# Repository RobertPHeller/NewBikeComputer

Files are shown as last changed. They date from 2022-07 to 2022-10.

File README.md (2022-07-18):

# New Bike Computer.

Based on the Adafruit ESP32-S3 TFT Feather, with an Adafruit Ultimate GPS
FeatherWing. Displays date/time, Lat/Lon, Heading, Alt., MPH/Miles, Battery
voltage. Saves trip info on SPIFFS, which is uploadable via USB.

This is an update to my older Ardunio Uno based unit. Improvements include the
GPS for location, time, heading, and altitude.  Using a 32-bit MCU and using 
FLASH SPIFFS to store trip information, as a CSV file, which can be uploaded
to a host computer via USB.  This version will be better weatherproofed (the 
old one's LCD display has been partially water damaged).

Files in this project:

NewBikeComputer.fzz -- this is the Fritzing for the circuit breadboard.  The 
circuit is pretty simple and straightforward.  If you don't have Fritzing, 
there is an image (NewBikeComputer_bb.png) of the breadboard and a PDF 
(NewBikeComputer_Schematic.pdf) of the schematic.  Parts placement is not 
critical.  Oh, the 100K resistor should be 107K: it and the 33K are 1% 
resistors that form a voltage divider to measure the battery voltage.  My 
trike has a 12V gell cell battery for the lights (headlights, marker lights, 
brake lights, and turn turn signals), that I am also using to power the bike 
computer.  If you are doing something else, feel free to modify things to 
suit.  If you use a LiPo, you can use the built-in JST connector and I believe 
there is a built in battery monitor circuit, so you should change that part of 
the code and leave off the 12V power supply, DC power jack, and the voltage 
divider resistors.

NewBikeComputer_bb.png -- Breadboard image

NewBikeComputer_Schematic.pdf -- Schematic

NewBikeComputer/ -- this sub-directorty contains the Arduino code:

- NewBikeComputer.ino This is the main program
- BikeNVS.h This is the NVS (EEProm) handling
- Button.cpp Button class
- Button.h   Button class
- Modes.cpp  Mode Button class
- Modes.h    Mode Button class
- PersistentTripDatabase.cpp Trip file handling
- PersistentTripDatabase.h   Trip file handling
- SerialCLI.cpp Serial CLI handling
- SerialCLI.h   Serial CLI handling
- Wheelsensor.cpp Wheel sensor
- Wheelsensor.h   Wheel sensor

Libraries needed: the Adafruit ST7735 and ST7789 library, the Adafruit GPS
library, the Adafruit BusIO library, and the Adafruit GFX (the last two will 
be pulled in by the first two).  If you use a LiPo battery and want to use the 
internal battery monitor, you will need to modify the code and add the  
Adafruit LC709203F library as well.

BikeHost/ -- this sub-directorty contains the host code.  This is a Tcl/Tk 
program that runs on a host computer to allow for some maintainance tasks and 
to upload the trip file.  It is set up to build under Linux for a Linux 
target. Note: the Arduino Serial Monitor could also be used for these 
functions.

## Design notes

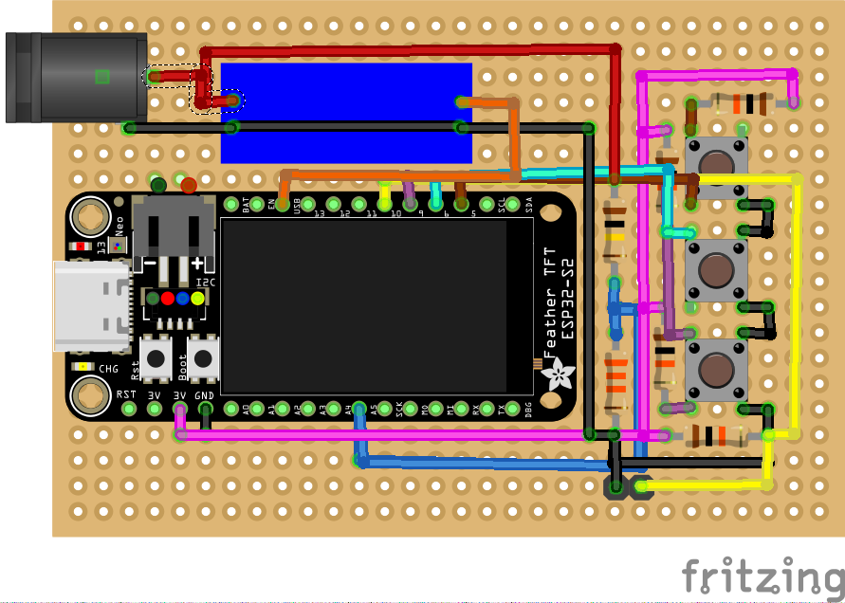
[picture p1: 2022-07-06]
NewBikeComputer_bb.png

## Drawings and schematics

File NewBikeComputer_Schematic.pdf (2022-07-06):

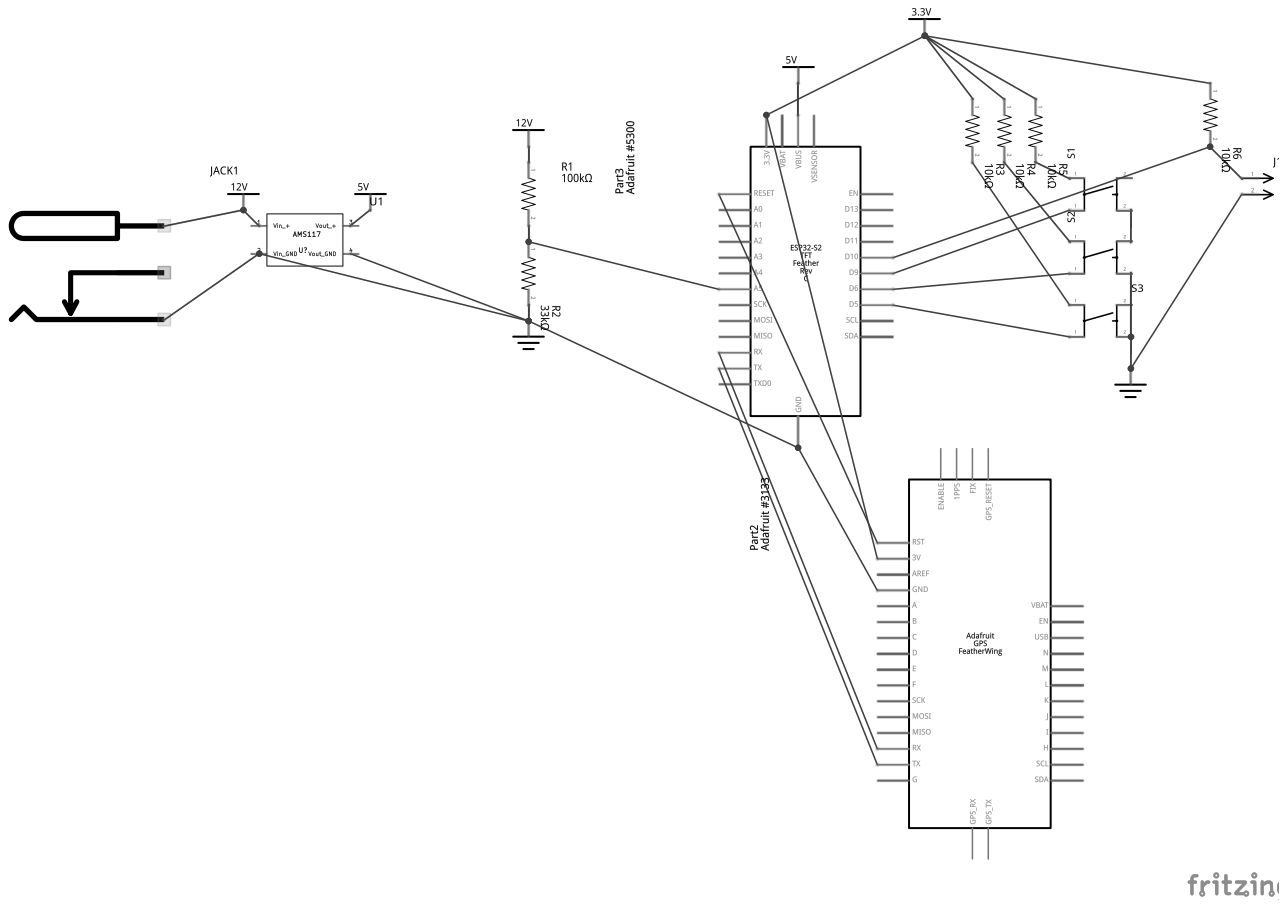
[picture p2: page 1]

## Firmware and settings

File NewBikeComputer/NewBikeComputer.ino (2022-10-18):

// -!- C++ -!- //////////////////////////////////////////////////////////////
//
//  System        : 
//  Module        : 
//  Object Name   : $RCSfile$
//  Revision      : $Revision$
//  Date          : $Date$
//  Author        : $Author$
//  Created By    : Robert Heller
//  Created       : Thu Jun 30 15:03:26 2022
//  Last Modified : <221018.1304>
//
//  Description	
//
//  Notes
//
//  History
//	
/////////////////////////////////////////////////////////////////////////////
//
//    Copyright (C) 2022  Robert Heller D/B/A Deepwoods Software
//			51 Locke Hill Road
//			Wendell, MA 01379-9728
//
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
// 
//
//////////////////////////////////////////////////////////////////////////////

static const char rcsid[] = "@(#) : $Id$";

#include <Arduino.h>
#include <stdio.h>
#include <Adafruit_GFX.h>    // Core graphics library
#include <Adafruit_ST7789.h> // Hardware-specific library for ST7789
#include <SPI.h>
#include <Adafruit_GPS.h>
#include <Fonts/FreeMono12pt7b.h> // 13x14 (WxH) Spacing: 14 NL: 24 -- 17c x 5l
#include <Fonts/FreeMono24pt7b.h> // 26x26 (WxH) Spacing: 28 NL: 47 -- 8c  x 2l
#include <HardwareSerial.h>
#include <FS.h>
#include <SPIFFS.h>
#include "Wheelsensor.h"
#include "Button.h"
#include "Modes.h"
#include "SerialCLI.h"
#include "PersistentTripDatabase.h"
#include "BikeNVS.h"

const uint8_t BUTTON2 = 9;
const uint8_t BUTTON3 = 6;
const uint8_t MODE  = 5;
const uint8_t WHEEL = 10;
const uint8_t BATTERY = A5;

Adafruit_GPS GPS(&Serial1);


ModeButton b1(MODE);
Button b2(BUTTON2);
Button b3(BUTTON3);
Wheelsensor WheelSensor(WHEEL);

// Use dedicated hardware SPI pins
Adafruit_ST7789 tft = Adafruit_ST7789(TFT_CS, TFT_DC, TFT_RST);
GFXcanvas16 canvas(240, 135);

PersistentTripDatabase tripdatabase(&GPS);

constexpr float VScale = 14.0/4095.0;

static     char buffer[40];

BikeNVS NVS;

static int TickCounter = 0;

void setup() {
    // put your setup code here, to run once:
    // Initialize serial first (so we can debug stuff)
    Serial.begin(115200);
    NVS.begin();
    // 9600 NMEA is the default baud rate for Adafruit MTK GPS's- some use 4800
    Serial1.begin(9600,SERIAL_8N1,RX,TX);
    delay(10);
    //GPS.begin(9600);
    GPS.sendCommand(PMTK_SET_NMEA_OUTPUT_RMCGGA);
    // Set the update rate
    GPS.sendCommand(PMTK_SET_NMEA_UPDATE_1HZ);   // 1 Hz update rate
    GPS.sendCommand(PMTK_API_SET_FIX_CTL_100_MILLIHERTZ);
    GPS.sendCommand(PGCMD_ANTENNA);
    delay(1000);
    GPS.sendCommand(PMTK_Q_RELEASE);
    WheelSensor.init(NVS.Miles());
    //analogReference(DEFAULT);
    // turn on backlite
    pinMode(TFT_BACKLITE, OUTPUT);
    digitalWrite(TFT_BACKLITE, HIGH);
    
    // turn on the TFT / I2C power supply
    pinMode(TFT_I2C_POWER, OUTPUT);
    digitalWrite(TFT_I2C_POWER, HIGH);
    delay(10);
    
    // initialize TFT
    tft.init(135, 240); // Init ST7789 240x135
    tft.setRotation(3);
    tft.fillScreen(ST77XX_BLACK);
    tripdatabase.begin(WheelSensor.Miles(),NVS.TZOffset());
    Serial.println("BikeComputer 0.0");
    Serial.print(">>");
    Serial.flush();
    TickCounter = 0;
}

void loop() {
    // put your main code here, to run repeatedly:
    // Get battery Voltage:
    float VBatt = analogRead(BATTERY) * VScale;
    int   VBint = (int)VBatt;
    int   VBfract = (int)((VBatt - VBint)*10);
    // Process any Serial CLI requests.
    if (Serial.available() > 0) {
        ProcessSerialCLI(&tripdatabase,&NVS,&WheelSensor);
    }
    // Read Wheel sensor and compute MPH
    int speed = 0;
    if (WheelSensor.CheckState()) {
        speed = WheelSensor.CurrentSpeed();
    }
    DisplayMode mode = TimeAndSpeed;
    //DisplayMode mode = b1.CheckModeButton();
    bool newtrip = false;
    // if (b2.Pressed()) newtrip = true;
    bool final   = false;
    // if (b3.Pressed()) final = true;
    tripdatabase.UpdateTripRecord(WheelSensor.Miles(),newtrip,final);
    canvas.fillScreen(ST77XX_BLACK);
    canvas.setFont(&FreeMono12pt7b);
    canvas.setCursor(0, 18);
    canvas.setTextColor(ST77XX_RED);
    canvas.println(tripdatabase.TimeHeader());
    canvas.setTextColor(ST77XX_YELLOW);
    canvas.println(tripdatabase.Location());
    canvas.println(tripdatabase.Heading());
    canvas.setTextColor(ST77XX_WHITE);
    canvas.setFont(&FreeMono24pt7b);
    canvas.setCursor(0, 104);
    //Serial.print("*** loop(): mode = "); Serial.println(mode);
    switch (mode)
    {
    case TimeAndSpeed:
        snprintf(buffer,sizeof(buffer),"%2d %4.1fV",speed,VBatt);
        break;
    case TimeAndDistance:
        snprintf(buffer,sizeof(buffer),"%6dM",WheelSensor.Miles());
        break;
    }
    canvas.println(buffer);
    //Serial.println(buffer);
    tft.drawRGBBitmap(0, 0, canvas.getBuffer(), 240, 135);
    TickCounter++;
    if ((TickCounter % 1000) == 0)
    {
        NVS.SetMiles(WheelSensor.Miles());
        NVS.commit();
    }
    delay(100);
}    

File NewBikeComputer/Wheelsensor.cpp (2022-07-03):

// -!- C++ -!- //////////////////////////////////////////////////////////////
//
//  System        : 
//  Module        : 
//  Object Name   : $RCSfile$
//  Revision      : $Revision$
//  Date          : $Date$
//  Author        : $Author$
//  Created By    : Robert Heller
//  Created       : Sun Sep 15 11:35:09 2013
//  Last Modified : <220703.1643>
//
//  Description	
//
//  Notes
//
//  History
//	
/////////////////////////////////////////////////////////////////////////////
//
//  Copyright (c) 2013 Deepwoods Software.
// 
//  All Rights Reserved.
// 
// This  document  may  not, in  whole  or in  part, be  copied,  photocopied,
// reproduced,  translated,  or  reduced to any  electronic  medium or machine
// readable form without prior written consent from Deepwoods Software.
//
//////////////////////////////////////////////////////////////////////////////

static const char rcsid[] = "@(#) : $Id$";

#include <Arduino.h>
#include "Wheelsensor.h"

/* Assumes 20 inch wheels */
#define FEETPERCYCLE ((PI * 20) / 12.0)
/* How many feet in a mile */
#define FEETPERMILE 5280

volatile int Wheelsensor::rotationcount = 0;

void Wheelsensor::init(float miles)
{
    lasttime = 0;
    totalmiles = miles;
    curspeed = 0;
    rotationcount = 0;
    attachInterrupt(digitalPinToInterrupt(pin_), count_rotation, RISING);
}

void Wheelsensor::count_rotation(void)
{
    rotationcount++;
}

bool Wheelsensor::CheckState()
{
    bool result = false;
    //delay(50);
    noInterrupts();
    long int cycletime = millis() - lasttime;
    int rc = rotationcount; rotationcount = 0;
    interrupts();
    if (rc > 0) {
        //Serial.print("*** Wheelsensor::CheckState(): lasttime = ");
        //Serial.print(lasttime);
        //Serial.print(", time is ");
        //Serial.println(millis());            
        //Serial.print("*** Wheelsensor::CheckState(): cycletime = ");
        //Serial.println(cycletime);
        // Time for next cycle
        lasttime = millis();
        // Compute speed
        curspeed = speed(cycletime / rc);
        //Serial.print("*** Wheelsensor::CheckState(): curspeed is ");
        //Serial.println(curspeed);
        // Accumulate distance
        totalmiles += rc * (FEETPERCYCLE / float(FEETPERMILE));
        //Serial.print("*** Wheelsensor::CheckState(): totalmiles = ");
        //Serial.println(totalmiles);
        result = true;
    }
    else {
        if (speed(cycletime) < 1) {
            curspeed = 0;
            result =  true;
        }
    }
    return result;
}

/** Compute speed in MPH, given a number of ms for a wheel
 *  * rotation,
 *  */
int Wheelsensor::speed(long int cycletime) {
    //Serial.print("*** Wheelsensor::speed(");
    //Serial.print(cycletime);
    //Serial.println(")");
    /* Convert cycle time to feet per second */
    double feetpersecond = (1000.0 / float(cycletime))*FEETPERCYCLE;
    //Serial.print("*** Wheelsensor::speed(): feetpersecond = ");
    //Serial.println(feetpersecond);
    /* Convert feet per second to feet per hour */
    double feetperhour   = feetpersecond * 3600;
    //Serial.print("*** Wheelsensor::speed(): feetperhour = ");
    //Serial.println(feetperhour);
    /* Convert feet per hour to whole miles per hour */
    int    milesperhour  = int((feetperhour / FEETPERMILE)); /* not rounding up */
    //Serial.print("*** Wheelsensor::speed(): milesperhour = ");
    //Serial.println(milesperhour);
    /* Return the MPH */
    return milesperhour;
}

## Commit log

2022-06-30 Add Panel and Board 3D models.
2022-07-03 Minor updates.
    [NewBikeComputer.fzz]
2022-07-04 Add Arduino CLI build script.
2022-07-06 Add Power supply parts. Create BB image and Schematic PDF.
    [NewBikeComputer.fzz]
2022-07-18 Add Bottom Spacer.
2022-08-05 Cut opening out of bottom spacer.
2022-08-05 Add cutout for board.
2022-08-05 Added board cutout.

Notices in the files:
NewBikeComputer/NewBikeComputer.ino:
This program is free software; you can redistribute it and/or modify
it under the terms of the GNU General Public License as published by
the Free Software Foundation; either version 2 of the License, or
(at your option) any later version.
